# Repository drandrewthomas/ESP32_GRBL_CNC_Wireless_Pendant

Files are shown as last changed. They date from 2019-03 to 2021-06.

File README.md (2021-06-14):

# ESP32 GRBL CNC pendant with Bluetooth data link

## Introduction

I have a small, cheap and cheerful, Chinese CNC machine that I use for routing and LASER cutting. It's really good but one thing it lacked compared to more professional machines was a proper pendant for me to jog and zero the XYZ axes. So, I decided to build one. While thinking about what microcontroller to use it dawned on me that if I used an ESP32 I could combine the pendant functions with a Bluetooth interface for sending G-Code over. After some coding, soldering and 3D printing I ended up with the design shown below.

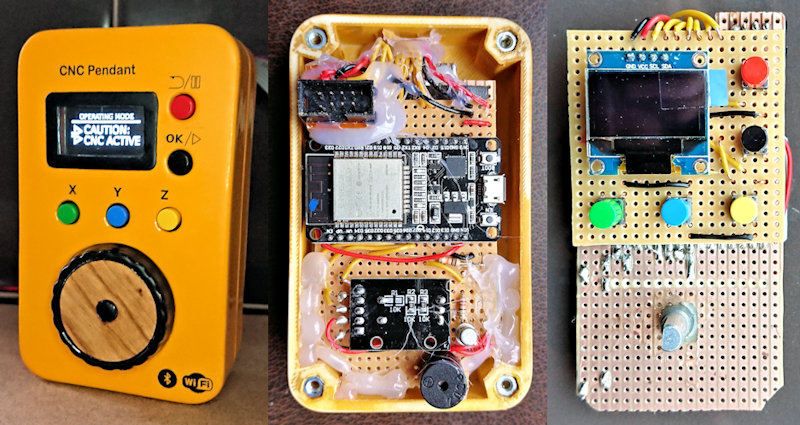
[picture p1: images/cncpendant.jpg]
Photos of the finished pendant and the circuit


## Building the pendant

One of the difficulties with a project like this is that there are a wide range of ESP32 modules available. So, it's not possible to give exact construction details. However, I thought I'd provide a few hints based on my experience designing it. The first is that all of the connections for switches, the OLED display and the rotary encoder module are in the Arduino code. It just involves running wires from those to the ESP32 board. To make life simple I wrote the code to use internal pullup resistors for the buttons. However, not all pins on all ESP32 boards have them, so if you have problems with a button not working you can add a 10k pullup resistor to it (you can see I had to do that with one button in the images folder).

The buzzer is a little more complicated as I used a 5V active one to get enough volume for it to be heard over the CNC machine. As it's 5V, and ESP32s are 3.3V, I used a 2n2222A transistor, with a 220 ohm resistor into it from the ESP32, for switching on and off, which works well. Another difficulty is the serial connection. Obviously you need to connect 5V and ground to the ESP32 (making sure to connect 5V to Vin, not 3.3V) and wire the Tx and Rx serial connections together between the CNC controller and ESP32. However, the connections vary between different GRBL CNC controller boards, so you'll need to sort that out for yourself based on which board you have. And if you have trouble getting output on your OLED display check that it is using I2C address 0x3c: some are set to use 0x3D in which case you need to change it using the solder jumper on the back or, more simply, change the address in the setup() function in the Arduino code. Also, please note that the Adafruit libraries now need you to install their busio library in the Arduino IDE to make them work without raising errors when compiling.

As for the case, it just involves 3D printing the parts provided in the '3d files' folder. You may need to adapt it for your use and for variations between ESP32 boards, so I've included the OpenSCAD file too. The photos should give enough info for you to lay out a piece of stripboard (a.k.a. veroboard) with the OLED display and buttons to fit the case openings. To mount the rotary encoder module I cut a hole in some stripboard and fixed the encoder to the back. The case includes holes in the corners that you can glue M3 nuts into to bolt the top and bottom of the case together. For the dial I decided to LASER cut some 1.5mm thick cherry wood, although you could change the OpenSCAD design to remove the need for that. However, if you decide to cut it there's an SVG included to help you out.

Finally, if your CNC controller board doesn't support 3.3V signals on the UART serial connection, you will need a level-convertor board to interface with the pendant. A cheap two channel one, such as sold for I2C level conversion, should do the job. If your CNC controller board has sufficient current limiting resistors on the serial transmit and receive pins (e.g. some Woodpecker ones have 100 ohm resistors) you may get away without level conversion, but for complete peace of mind it's safest to add level conversion to prevent frying your ESP32 circuits.

## Parts list

The exact parts needed will depend on how you decide to build the project, but the list below is what I used, in case you find it useful:

* 1x 0.96 Inch SSD1306 OLED I2C Display 128x64 pixels

* 5x PCB mounting push switches

* 1x Arduino rotary encoder module brick on PCB

* 1x ESP32 board (I used an ESP32 DOIT DevKit v1)

* 1x 220-ohm resistor

* 1x 2n2222A transistor

* 1x 5V mini active buzzer

* 4x M3 nuts and bolts

* 10 k-ohm pullup resistors for push switches where needed

## Using the pendant

When you power up the pendant (usually through your cable to the CNC controller board) it'll show a splash screen and soon after start in operating mode (as in the photo above). That means it will pass through any commands sent between your PC/tablet and the CNC controller. Basically that means it'll act just like any other wireless or wired way of sending G-Code to your CNC. To connect via Bluetooth you'll need to know the pendants' identifier, which is 'CNCESP32'.

From the operating mode you can use the OK button to access a menu of other functions: jogging mode, zeroing mode and focusing mode. The modes are quite easy to change or add to in the code if they don't suit your needs. Use the rotary encoder dial to scroll through them. The OK button then lets you enter that mode. In jogging mode you can choose the axis to move using the XYZ buttons and turn the dial clockwise and counter-clockwise to move the selected axis. For coarser, faster, movement press the rotary encoder dial down while turning, as the encoder has a switch built in. Coarser movement goes three times further than normal jogging, so please be careful until you get the hang of it.

In zeroing mode you can press an XYZ button and the pendant will tell the CNC controller to zero that axis at the current position. To zero all axes just press the XYZ buttons one at a time, waiting for a confirmation beep in between. The final mode is the focusing one, which is only of use if you have a LASER module. Basically it turns on the LASER at a low power level: I set the value for my 5W dode-LASER so please adjust it to suit your own LASER so as to minimise injury and damage risks. The first time you enter this mode the LASER will turn on, allowing you to focus it or to go back to jogging mode to set your origin position with a visible LASER-dot. The second time will turn the LASER off, although it'll also turn off automatically if you exit back to operating mode (all modes and menus can be exited with the BACK button).

## And finally!

If you'd like to read my blog-post about this project [please click here to visit it](https://cncmakerzone.co.uk/make-a-grbl-cnc-pendant-with-a-bluetooth-data-link).

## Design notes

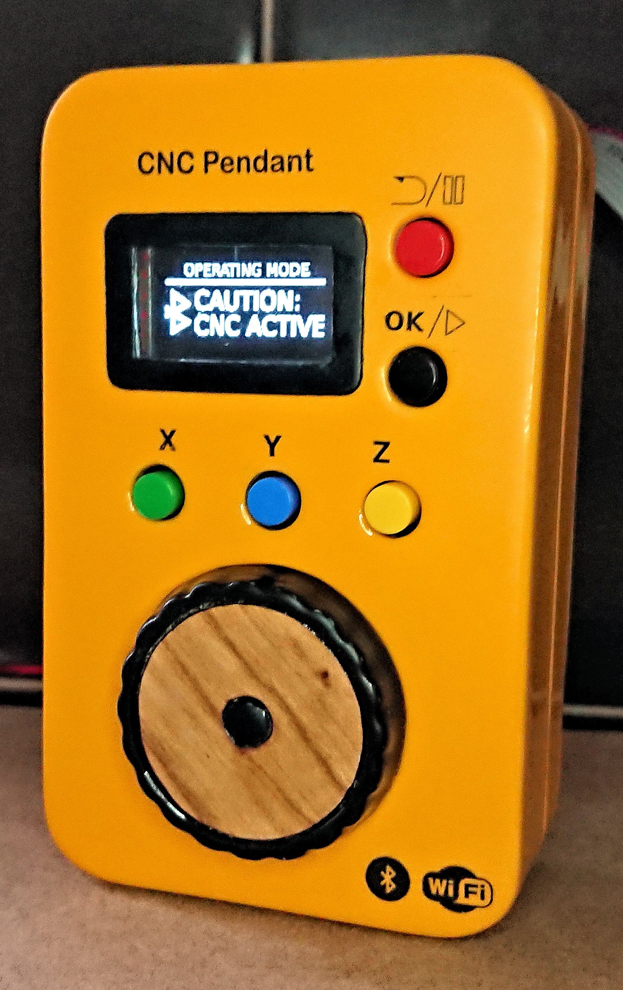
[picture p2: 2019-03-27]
images/cncpendant_front.jpg

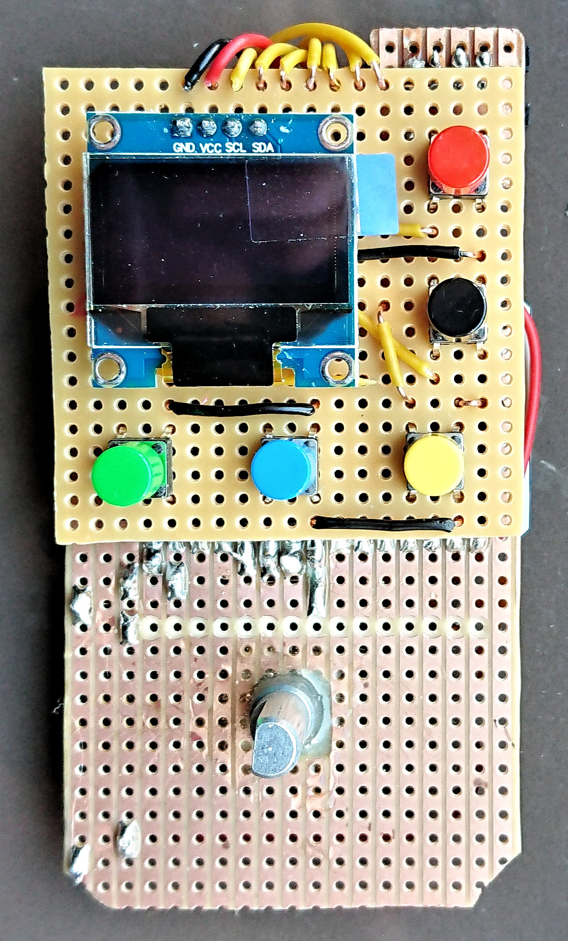
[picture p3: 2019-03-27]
images/cncpendant_layout.jpg

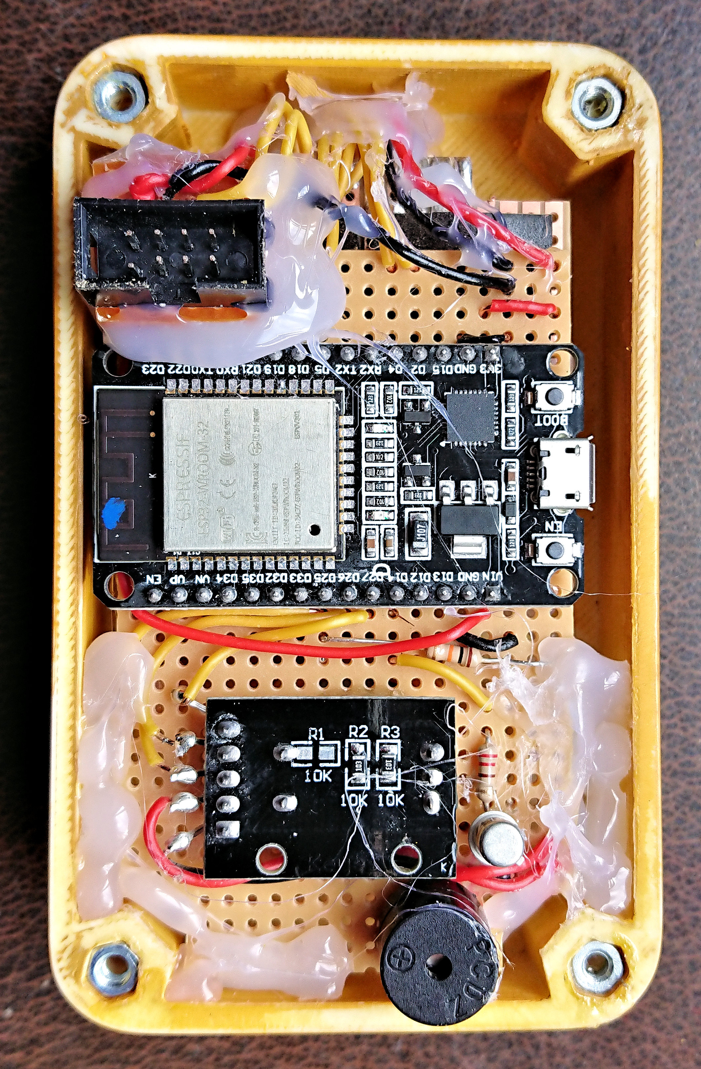
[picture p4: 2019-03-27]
images/cncpendant_inside.jpg

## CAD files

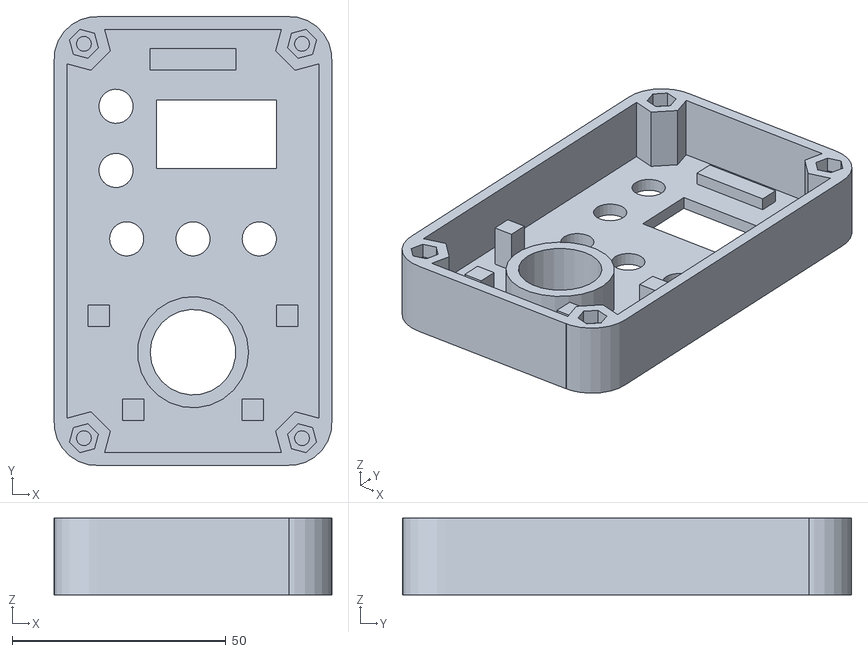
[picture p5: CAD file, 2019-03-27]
3dfiles/cncminipendant_top.stl
65.0 x 105.0 x 18.0

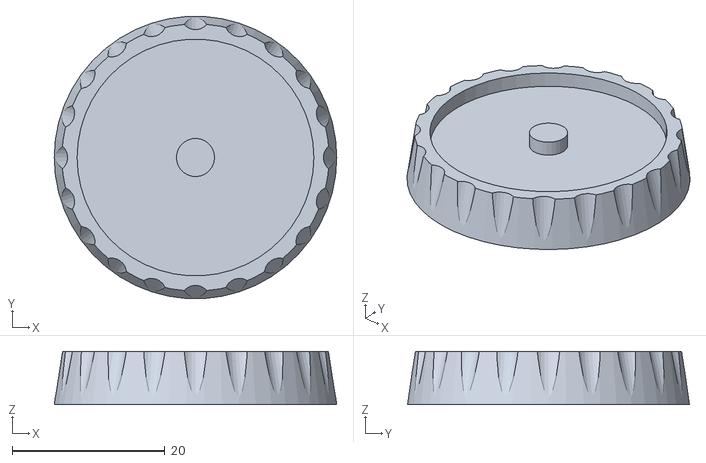
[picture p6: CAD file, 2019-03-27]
3dfiles/cncminipendant_dialtop.stl
37.0 x 36.9 x 7.00

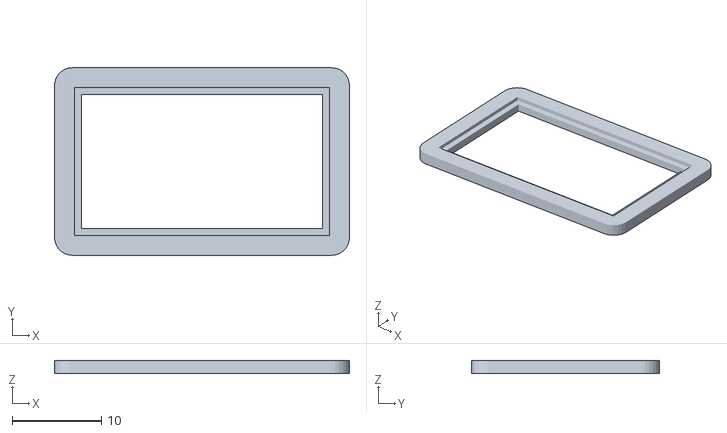
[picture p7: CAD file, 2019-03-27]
3dfiles/cncminipendant_lcdbezel.stl
33.0 x 21.0 x 1.50

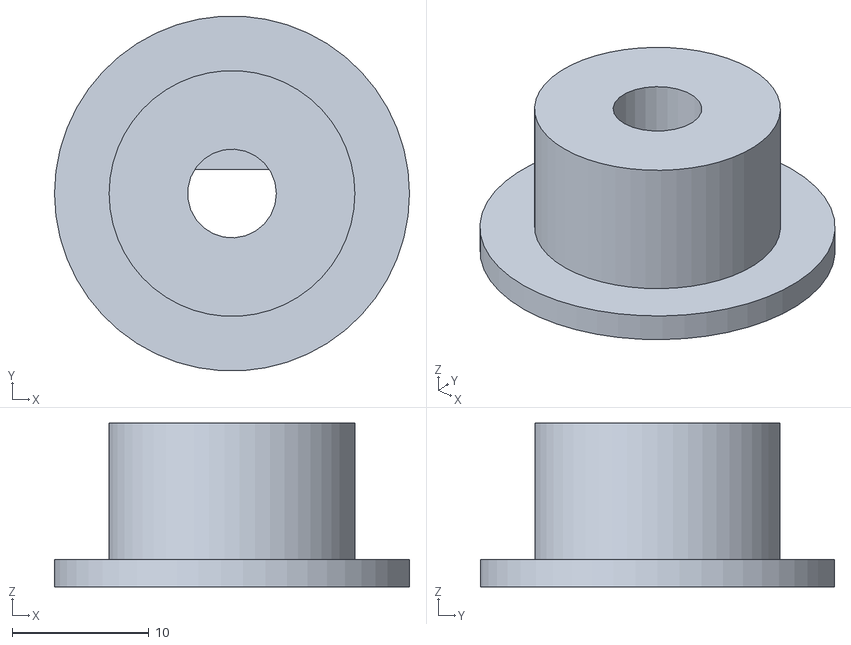
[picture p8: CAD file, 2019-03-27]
3dfiles/cncminipendant_dialbase.stl
26.0 x 25.9 x 12.0

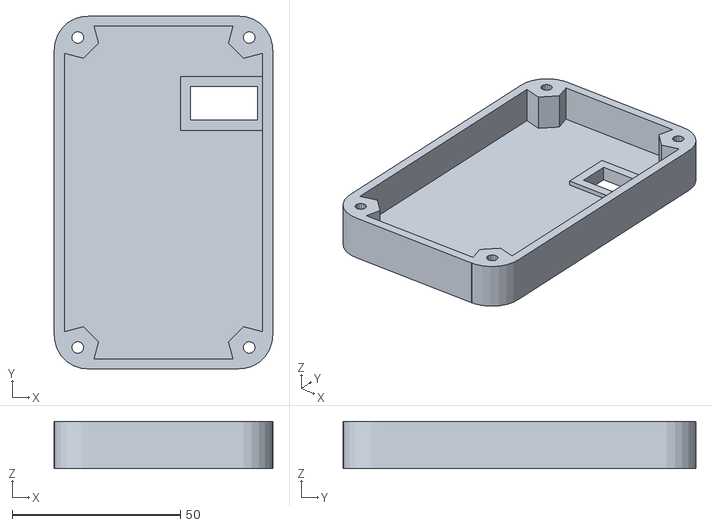
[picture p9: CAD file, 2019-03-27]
3dfiles/cncminipendant_bottom.stl
65.0 x 105.0 x 14.0

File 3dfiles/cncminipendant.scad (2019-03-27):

$fn=25;

//maketop();
//makelcdbezel();
//makedialbase();
//makedialtop();
makebottom();

module makebottom()
{
  render() difference()
  {
    render() union()
    {
      render() difference()
      {
        translate([0,-0.5,0]) roundedbox(55+4+6,96+3+6,14,10);
        translate([0,-0.5,3]) roundedbox(55+4,96+3,14,7);
      }
      translate([32-10-4,52.5-0.5-5-21,-5.5+1.9]) cube([26,16,2],center=true);
      translate([-24-1.5,(96/2)-0.5-1.9,0]) rotate([0,0,45]) cylinder(h=14,r1=12.8/2,r2=12.8/2,$fn=6,center=true);
      translate([24+1.5,(96/2)-0.5-1.9,0]) rotate([0,0,-45]) cylinder(h=14,r1=12.8/2,r2=12.8/2,$fn=6,center=true);
      translate([-24-1.5,-(96/2)-0.5+1.9,0]) rotate([0,0,15]) cylinder(h=14,r1=12.8/2,r2=12.8/2,$fn=6,center=true);
      translate([24+1.5,-(96/2)-0.5+1.9,0]) rotate([0,0,-15]) cylinder(h=14,r1=12.8/2,r2=12.8/2,$fn=6,center=true);
    }
    translate([-24-1.5,(96/2)-0.5-1.9,0]) cylinder(h=20,r1=3.5/2,r2=3.5/2,$fn=15,center=true);
    translate([24+1.5,(96/2)-0.5-1.9,0]) cylinder(h=20,r1=3.5/2,r2=3.5/2,$fn=15,center=true);
    translate([-24-1.5,-(96/2)-0.5+1.9,0]) cylinder(h=20,r1=3.5/2,r2=3.5/2,$fn=15,center=true);
    translate([24+1.5,-(96/2)-0.5+1.9,0]) cylinder(h=20,r1=3.5/2,r2=3.5/2,$fn=15,center=true);
    render() difference()
    {
      translate([0,-0.5,0]) roundedbox(100+55+4+6,100+96+3+6,18,10);
      translate([0,-0.5,0]) roundedbox(55+4+6,96+3+6,100,10);
    }
    translate([32-10-4,52.5-0.5-5-21,0]) cube([20,10,20],center=true);
  }
}

module makedialtop()
{
  union()
  {
    difference()
    {
      translate([0,0,0]) cylinder(h=7,r1=37/2,r2=35/2,$fn=50,center=true);
      translate([0,0,-3.5]) cylinder(h=6,r1=26.5/2,r2=26.5/2,$fn=50,center=true);
      translate([0,0,3.5]) cylinder(h=4,r1=31/2,r2=31/2,$fn=50,center=true);
      for(c=[0:20])
        rotate([0,0,c*(360/20)])
          translate([-19.75,0,0])
            rotate([0,15,0])
              cylinder(h=30,r1=4/2,r2=4/2,$fn=25,center=true);
    }
    translate([0,0,3.5-1.1]) cylinder(h=2.1,r1=5/2,r2=5/2,$fn=25,center=true);
  }
}

module makedialbase()
{
  rotate([180,0,0])
  {
    difference()
    {
      union()
      {
        translate([0,0,1]) cylinder(h=12,r1=18/2,r2=18/2,$fn=50,center=true);
        translate([0,0,1+6-1]) cylinder(h=2,r1=26/2,r2=26/2,$fn=50,center=true);
      }
      difference()
      {
        translate([0,0,0]) cylinder(h=20,r1=6.5/2,r2=6.5/2,center=true);
        translate([0,-(6.5/2)-0.5,10-1]) cube([10,4,20],center=true);
      }
    }
  }
}

module makelcdbezel()
{
  rotate([0,180,0])
  {
    difference()
    {
      translate([0,0,0]) roundedbox(27+6,15+6,1.5,2);
      translate([0,0,0]) cube([27,15,50],center=true);
      translate([0,0,-1]) cube([27+1.5,15+1.5,1.5],center=true);
    }
  }
}

module maketop()
{
  difference()
  {
    union()
    {
      difference()
      {
        translate([0,-0.5,0]) roundedbox(55+4+6,96+3+6,18,10);
        translate([0,-0.5,3]) roundedbox(55+4,96+3,18,7);
      }
      translate([0,-(96/2)+48-26.5,-9+5+1.5]) cylinder(h=10+3,r1=26/2,r2=26/2,$fn=25,center=true);
      translate([-14,-40,-9+5+1.5]) cube([5,5,10+3],center=true);
      translate([14,-40,-9+5+1.5]) cube([5,5,10+3],center=true);
      translate([-22,-18,-9+5+1.5]) cube([5,5,10+3],center=true);
      translate([22,-18,-9+5+1.5]) cube([5,5,10+3],center=true);
      translate([0,42,-9+1.5+1.5]) cube([20,5,3+3],center=true);
      translate([-24-1.5,(96/2)-0.5-1.9,0]) rotate([0,0,45]) cylinder(h=18,r1=12.8/2,r2=12.8/2,$fn=6,center=true);
      translate([24+1.5,(96/2)-0.5-1.9,0]) rotate([0,0,-45]) cylinder(h=18,r1=12.8/2,r2=12.8/2,$fn=6,center=true);
      translate([-24-1.5,-(96/2)-0.5+1.9,0]) rotate([0,0,15]) cylinder(h=18,r1=12.8/2,r2=12.8/2,$fn=6,center=true);
      translate([24+1.5,-(96/2)-0.5+1.9,0]) rotate([0,0,-15]) cylinder(h=18,r1=12.8/2,r2=12.8/2,$fn=6,center=true);
    }
    translate([0,0,0]) rotate([0,180,0]) controls();
    translate([-24-1.5,(96/2)-0.5-1.9,18-3.5]) rotate([0,0,45]) cylinder(h=18,r1=7/2,r2=7/2,$fn=6,center=true);
    translate([24+1.5,(96/2)-0.5-1.9,18-3.5]) rotate([0,0,-45]) cylinder(h=18,r1=7/2,r2=7/2,$fn=6,center=true);
    translate([-24-1.5,-(96/2)-0.5+1.9,18-3.5]) rotate([0,0,15]) cylinder(h=18,r1=7/2,r2=7/2,$fn=6,center=true);
    translate([24+1.5,-(96/2)-0.5+1.9,18-3.5]) rotate([0,0,-15]) cylinder(h=18,r1=7/2,r2=7/2,$fn=6,center=true);
    translate([-24-1.5,(96/2)-0.5-1.9,5]) cylinder(h=18,r1=3.5/2,r2=3.5/2,$fn=15,center=true);
    translate([24+1.5,(96/2)-0.5-1.9,5]) cylinder(h=18,r1=3.5/2,r2=3.5/2,$fn=15,center=true);
    translate([-24-1.5,-(96/2)-0.5+1.9,5]) cylinder(h=18,r1=3.5/2,r2=3.5/2,$fn=15,center=true);
    translate([24+1.5,-(96/2)-0.5+1.9,5]) cylinder(h=18,r1=3.5/2,r2=3.5/2,$fn=15,center=true);
    difference()
    {
      translate([0,-0.5,0]) roundedbox(100+55+4+6,100+96+3+6,18,10);
      translate([0,-0.5,0]) roundedbox(55+4+6,96+3+6,100,10);
    }
  }
}

module controls()
{
  translate([-(55/2)+5+(27/2)+4.5-1,-(96/2)+65.5+(15/2)-0.5,0]) cube([27+1,15+1,50],center=true);
  translate([(55/2)-9.5,-(96/2)+79,0]) cylinder(h=50,r1=8/2,r2=8/2,center=true);
  translate([(55/2)-9.5,-(96/2)+64,0]) cylinder(h=50,r1=8/2,r2=8/2,center=true);
  translate([-15.5,-(96/2)+48,0]) cylinder(h=50,r1=8/2,r2=8/2,center=true);
  translate([0,-(96/2)+48,0]) cylinder(h=50,r1=8/2,r2=8/2,center=true);
  translate([15.5,-(96/2)+48,0]) cylinder(h=50,r1=8/2,r2=8/2,center=true);
  translate([0,-(96/2)+48-26.5,0]) cylinder(h=50,r1=20/2,r2=20/2,$fn=25,center=true);
}

module roundedbox(l,d,h,r)
{
  difference()
  {
    difference()
    {
      difference()
      {
        difference()
        {
          cube([l,d,h],center=true);
          translate([-(l/2)+r,-(d/2)+r,0]){corner(r,h,0);};
        }
        translate([(l/2)-r,-(d/2)+r,0]){corner(r,h,90);};
      }
      translate([(l/2)-r,(d/2)-r,0]){corner(r,h,180);};
    }
    translate([-(l/2)+r,(d/2)-r,0]){corner(r,h,270);};
  }
}

module corner(r,h,ang)
{
  rotate([0,0,ang])
  {
    difference()
    {
      difference()
      {
        difference()
        {
          cylinder(h*2,r*2,r*2,center=true);
          cylinder(h*2,r,r,center=true);
        }
        translate([r*5,0,0]){cube([r*10,r*10,h*2],center=true);}
      }
      translate([0,r*5,0]){cube([r*10,r*10,h*2],center=true);}
    }
  }
}

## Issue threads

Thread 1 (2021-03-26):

Blank screen after uploaded successfully

RepRapThailand, 2021-03-26:
Hello,

  I tried many times to upload your sketch, but it failed every time. When I try to upload sample sketch "ssd1306_128x32_i2c" and success every time there is a picture on the screen.

 Best Regards,

**Blank screen with your sketch.**

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

**ssd1306_128x32_i2c  sketch.**

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

drandrewthomas, 2021-03-26:
Hi,

Sorry to hear you're having problems. I checked and my I2C wiring seems the same as yours, so odd yours didn't work. So could you try the three ideas below (my guess is it's number 3):

1. Have you used the serial console to see if the library is printing an error?

2. If you look in setup() you'll see the pinMode lines. The ones that have INPUT, rather than INPUT_PULLUP, will have floating voltages unless you use 10k pullup resistors on those pins. That could interfere with operation so I can't guarantee the code will work unless you build the full circuit.

3. I was a bit confused by your screenshot of the example code, as it suggests you're using code for a 128x32 oled, which I think often have an I2C address of 0x3D. Looking at one of my OLED displays I notice it has an address changing jumper on the back that seems to be set for 0x3D. So can you check what address your oled is set to (or you could use the arduino i2c detect sketch). My guess is that changing the 0x3C address in setup(), for the oled setup line, to 0x3D will solve your problem.

Let me know if that helps, or if you still get a problem.

Best wishes,

Andrew.

RepRapThailand, 2021-03-27:
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

Hi,

1.
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

2. Not try yet.

3. I try with ssd1306_128x64_i2c sketch and it work too. I use Arduino i2c detect sketch scan my OLED and it show 0x3C.

Best Regards,
KK.

RepRapThailand, 2021-03-27:
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

#include <Wire.h>
#include <Adafruit_GFX.h>
#include <Adafruit_SSD1306.h>
#define SCREEN_WIDTH 128
#define SCREEN_HEIGHT 64
Adafruit_SSD1306 display(SCREEN_WIDTH, SCREEN_HEIGHT, &Wire, -1);
static const uint8_t image_data[1024] = {
   0xff, 0xff, 0xff, 0xff, 0xff, 0xff, 0xff, 0xff, 0xff, 0xff, 0xff, 0xff, 0xff, 0xff, 0xff, 0xff,
0xff, 0xff, 0xff, 0xff, 0xff, 0xff, 0xff, 0xff, 0xff, 0xff, 0xff, 0xff, 0xff, 0xff, 0xff, 0xff,
0xff, 0xff, 0xff, 0xff, 0xff, 0xff, 0xff, 0xff, 0xff, 0xff, 0xff, 0xff, 0xff, 0xff, 0xff, 0xff,
0xff, 0xff, 0xff, 0xff, 0xff, 0xff, 0xff, 0xff, 0xff, 0xff, 0xff, 0xff, 0xff, 0xff, 0xff, 0xff,
0xff, 0xff, 0xff, 0xff, 0xff, 0xff, 0xff, 0xff, 0xff, 0xff, 0xff, 0xff, 0xff, 0xff, 0xff, 0xff,
0xff, 0xff, 0xff, 0xff, 0xff, 0xff, 0xff, 0xff, 0xff, 0xff, 0xff, 0xff, 0xff, 0xff, 0xff, 0xff,
0xff, 0xff, 0xff, 0xff, 0xff, 0xff, 0xff, 0xff, 0xff, 0xff, 0xff, 0xff, 0xff, 0xff, 0xff, 0xff,
0xff, 0xff, 0xff, 0xff, 0xff, 0xff, 0xff, 0xff, 0xff, 0xff, 0xff, 0xff, 0xff, 0xff, 0xff, 0xff,
0xff, 0xff, 0xff, 0xff, 0xff, 0xfb, 0xff, 0xff, 0xff, 0xff, 0xdf, 0xff, 0xff, 0xff, 0xff, 0xff,
0xff, 0xff, 0xff, 0xff, 0xfc, 0x00, 0x00, 0xff, 0xff, 0x00, 0x00, 0x3f, 0xff, 0xff, 0xff, 0xff,
0xff, 0xff, 0xff, 0xff, 0xe0, 0x00, 0x00, 0x1f, 0xf8, 0x00, 0x00, 0x07, 0xff, 0xff, 0xff, 0xff,
0xff, 0xff, 0xff, 0xff, 0xf0, 0x20, 0x00, 0x0f, 0xf0, 0x00, 0x04, 0x0f, 0xff, 0xff, 0xff, 0xff,
0xff, 0xff, 0xff, 0xff, 0xf0, 0x0e, 0x00, 0x07, 0xe0, 0x00, 0x60, 0x0f, 0xff, 0xff, 0xff, 0xff,
0xff, 0xff, 0xff, 0xff, 0xe0, 0x01, 0xe0, 0x03, 0xc0, 0x07, 0x80, 0x07, 0xff, 0xff, 0xff, 0xff,
0xff, 0xff, 0xff, 0xff, 0xf8, 0x00, 0x3c, 0x03, 0xc0, 0x3c, 0x00, 0x1f, 0xff, 0xff, 0xff, 0xff,
0xff, 0xff, 0xff, 0xff, 0xf8, 0x00, 0x07, 0x87, 0xe1, 0xe0, 0x00, 0x1f, 0xff, 0xff, 0xff, 0xff,
0xff, 0xff, 0xff, 0xff, 0xfe, 0x00, 0x01, 0xff, 0xff, 0x80, 0x00, 0x7f, 0xff, 0xff, 0xff, 0xff,
0xff, 0xff, 0xff, 0xff, 0xff, 0x00, 0x00, 0x7f, 0xfe, 0x00, 0x00, 0xff, 0xff, 0xff, 0xff, 0xff,
0xff, 0xff, 0xff, 0xff, 0xff, 0x80, 0x00, 0xff, 0xff, 0x00, 0x01, 0xff, 0xff, 0xff, 0xff, 0xff,
0xff, 0xff, 0xff, 0xff, 0xff, 0xf0, 0x01, 0xff, 0xff, 0x80, 0x0f, 0xff, 0xff, 0xff, 0xff, 0xff,
0xff, 0xff, 0xff, 0xff, 0xff, 0xfe, 0x3f, 0xff, 0xff, 0xfc, 0x7f, 0xff, 0xff, 0xff, 0xff, 0xff,
0xff, 0xff, 0xff, 0xff, 0xff, 0xff, 0xff, 0xf0, 0x0f, 0xff, 0xff, 0xff, 0xff, 0xff, 0xff, 0xff,
0xff, 0xff, 0xff, 0xff, 0xff, 0xfc, 0x0f, 0x80, 0x01, 0xc0, 0x7f, 0xff, 0xff, 0xff, 0xff, 0xff,
0xff, 0xff, 0xff, 0xff, 0xff, 0xe0, 0x1e, 0x00, 0x00, 0x60, 0x0f, 0xff, 0xff, 0xff, 0xff, 0xff,
0xff, 0xff, 0xff, 0xff, 0xff, 0x80, 0x3e, 0x00, 0x00, 0x78, 0x03, 0xff, 0xff, 0xff, 0xff, 0xff,
0xff, 0xff, 0xff, 0xff, 0xfe, 0x00, 0xff, 0x00, 0x00, 0xfe, 0x01, 0xff, 0xff, 0xff, 0xff, 0xff,
0xff, 0xff, 0xff, 0xff, 0xfe, 0x03, 0xff, 0xe0, 0x03, 0xff, 0x80, 0xff, 0xff, 0xff, 0xff, 0xff,
0xff, 0xff, 0xff, 0xff, 0xfc, 0x0f, 0xff, 0xff, 0xff, 0xff, 0xe0, 0x7f, 0xff, 0xff, 0xff, 0xff,
0xff, 0xff, 0xff, 0xff, 0xfc, 0x7f, 0x00, 0x3f, 0xf8, 0x00, 0xfc, 0x7f, 0xff, 0xff, 0xff, 0xff,
0xff, 0xff, 0xff, 0xff, 0xff, 0xfc, 0x00, 0x0f, 0xf0, 0x00, 0x3f, 0xff, 0xff, 0xff, 0xff, 0xff,
0xff, 0xff, 0xff, 0xff, 0xff, 0xf8, 0x00, 0x07, 0xe0, 0x00, 0x1f, 0xff, 0xff, 0xff, 0xff, 0xff,
0xff, 0xff, 0xff, 0xff, 0xf3, 0xf0, 0x00, 0x07, 0xc0, 0x00, 0x0f, 0x8f, 0xff, 0xff, 0xff, 0xff,
0xff, 0xff, 0xff, 0xff, 0xc3, 0xe0, 0x00, 0x03, 0xc0, 0x00, 0x07, 0x03, 0xff, 0xff, 0xff, 0xff,
0xff, 0xff, 0xff, 0xff, 0x01, 0xc0, 0x00, 0x03, 0xc0, 0x00, 0x07, 0x01, 0xff, 0xff, 0xff, 0xff,
0xff, 0xff, 0xff, 0xff, 0x01, 0xc0, 0x00, 0x07, 0xe0, 0x00, 0x07, 0x01, 0xff, 0xff, 0xff, 0xff,
0xff, 0xff, 0xff, 0xfe, 0x01, 0xc0, 0x00, 0x07, 0xf0, 0x00, 0x07, 0x80, 0xff, 0xff, 0xff, 0xff,
0xff, 0xff, 0xff, 0xfe, 0x03, 0xe0, 0x00, 0x0f, 0xf8, 0x00, 0x0f, 0x80, 0xff, 0xff, 0xff, 0xff,
0xff, 0xff, 0xff, 0xfe, 0x03, 0xf0, 0x00, 0x3f, 0xfc, 0x00, 0x1f, 0x80, 0xff, 0xff, 0xff, 0xff,
0xff, 0xff, 0xff, 0xff, 0x07, 0xfc, 0x00, 0xff, 0xff, 0x80, 0x3f, 0xc1, 0xff, 0xff, 0xff, 0xff,
0xff, 0xff, 0xff, 0xff, 0x87, 0xff, 0xff, 0xc0, 0x03, 0xff, 0xff, 0xc3, 0xff, 0xff, 0xff, 0xff,
0xff, 0xff, 0xff, 0xff, 0xcf, 0xff, 0xff, 0x00, 0x00, 0xff, 0xff, 0xf7, 0xff, 0xff, 0xff, 0xff,
0xff, 0xff, 0xff, 0xff, 0xfe, 0x3f, 0xfe, 0x00, 0x00, 0x7f, 0xe0, 0x3f, 0xff, 0xff, 0xff, 0xff,
0xff, 0xff, 0xff, 0xff, 0xf8, 0x07, 0xfc, 0x00, 0x00, 0x3f, 0x80, 0x1f, 0xff, 0xff, 0xff, 0xff,
0xff, 0xff, 0xff, 0xff, 0xf8, 0x01, 0xfc, 0x00, 0x00, 0x3e, 0x00, 0x1f, 0xff, 0xff, 0xff, 0xff,
0xff, 0xff, 0xff, 0xff, 0xf8, 0x00, 0x7c, 0x00, 0x00, 0x3c, 0x00, 0x1f, 0xff, 0xff, 0xff, 0xff,
0xff, 0xff, 0xff, 0xff, 0xf8, 0x00, 0x3c, 0x00, 0x00, 0x38, 0x00, 0x1f, 0xff, 0xff, 0xff, 0xff,
0xff, 0xff, 0xff, 0xff, 0xf8, 0x00, 0x1e, 0x00, 0x00, 0x70, 0x00, 0x3f, 0xff, 0xff, 0xff, 0xff,
0xff, 0xff, 0xff, 0xff, 0xfc, 0x00, 0x1f, 0x80, 0x01, 0xf0, 0x00, 0x3f, 0xff, 0xff, 0xff, 0xff,
0xff, 0xff, 0xff, 0xff, 0xfe, 0x00, 0x0f, 0xe0, 0x07, 0xe0, 0x00, 0xff, 0xff, 0xff, 0xff, 0xff,
0xff, 0xff, 0xff, 0xff, 0xff, 0x80, 0x0f, 0xff, 0xff, 0xf0, 0x03, 0xff, 0xff, 0xff, 0xff, 0xff,
0xff, 0xff, 0xff, 0xff, 0xff, 0xf0, 0x1f, 0xff, 0xff, 0xf0, 0x0f, 0xff, 0xff, 0xff, 0xff, 0xff,
0xff, 0xff, 0xff, 0xff, 0xff, 0xff, 0xff, 0xc0, 0x03, 0xff, 0xff, 0xff, 0xff, 0xff, 0xff, 0xff,
0xff, 0xff, 0xff, 0xff, 0xff, 0xff, 0xfe, 0x00, 0x00, 0x7f, 0xff, 0xff, 0xff, 0xff, 0xff, 0xff,
0xff, 0xff, 0xff, 0xff, 0xff, 0xff, 0xfc, 0x00, 0x00, 0x7f, 0xff, 0xff, 0xff, 0xff, 0xff, 0xff,
0xff, 0xff, 0xff, 0xff, 0xff, 0xff, 0xff, 0x00, 0x00, 0xff, 0xff, 0xff, 0xff, 0xff, 0xff, 0xff,
0xff, 0xff, 0xff, 0xff, 0xff, 0xff, 0xff, 0xc0, 0x07, 0xff, 0xff, 0xff, 0xff, 0xff, 0xff, 0xff,
0xff, 0xff, 0xff, 0xff, 0xff, 0xff, 0xff, 0xff, 0xff, 0xff, 0xff, 0xff, 0xff, 0xff, 0xff, 0xff,
0xff, 0xff, 0xff, 0xff, 0xff, 0xff, 0xff, 0xff, 0xff, 0xff, 0xff, 0xff, 0xff, 0xff, 0xff, 0xff,
0xff, 0xff, 0xff, 0xff, 0xff, 0xff, 0xff, 0xff, 0xff, 0xff, 0xff, 0xff, 0xff, 0xff, 0xff, 0xff,
0xff, 0xff, 0xff, 0xff, 0xff, 0xff, 0xff, 0xff, 0xff, 0xff, 0xff, 0xff, 0xff, 0xff, 0xff, 0xff,
0xff, 0xff, 0xff, 0xff, 0xff, 0xff, 0xff, 0xff, 0xff, 0xff, 0xff, 0xff, 0xff, 0xff, 0xff, 0xff,
0xff, 0xff, 0xff, 0xff, 0xff, 0xff, 0xff, 0xff, 0xff, 0xff, 0xff, 0xff, 0xff, 0xff, 0xff, 0xff,
0xff, 0xff, 0xff, 0xff, 0xff, 0xff, 0xff, 0xff, 0xff, 0xff, 0xff, 0xff, 0xff, 0xff, 0xff, 0xff,
0xff, 0xff, 0xff, 0xff, 0xff, 0xff, 0xff, 0xff, 0xff, 0xff, 0xff, 0xff, 0xff, 0xff, 0xff, 0xff
};
void setup() {
  Serial.begin(115200);
  if(!display.begin(SSD1306_SWITCHCAPVCC, 0x3C)) {
    Serial.println(F("SSD1306 allocation failed"));
    for(;;);
  }
  delay(2000); // Pause for 2 seconds
  // Clear the buffer.
   display.clearDisplay();
  testscrolltext();
  // Clear the buffer.
  display.clearDisplay();
  // Draw bitmap on the screen
  display.drawBitmap(0, 0, image_data, 128, 64, 1);
  display.display();
}
 void testscrolltext(void) {
  display.clearDisplay(); // clear the display screen of the OLED
  display.setTextSize(2); // Draw 2X-scale text
  display.setTextColor(WHITE);
  display.setCursor(0, 0);
  display.println(F("Welcome"));
  delay(2000);
  display.clearDisplay();
  display.println(F("Coming Up"));
  display.println(F("RPi logo"));
  display.display();
  delay(100);
  display.startscrollright(0x00, 0x0F);
  delay(2000);
  display.stopscroll();
  delay(1000);
  display.startscrollleft(0x00, 0x0F);
  delay(2000);
  display.stopscroll();
  delay(1000);
  display.startscrolldiagright(0x00, 0x07);
  delay(2000);
  display.startscrolldiagleft(0x00, 0x07);
  delay(2000);
  display.stopscroll();
  delay(1000);
}
void loop() {
}

RepRapThailand, 2021-03-27:
not success..

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

#include <SPI.h>
#include <Wire.h>
#include <Adafruit_GFX.h>
#include <Adafruit_SSD1306.h>

Adafruit_SSD1306 display(-1);
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
drandrewthomas, 2021-03-27:
Hi,

Thanks for trying that and for the info. I wired up an OLED to the same ESP32 board as you, with the same wiring, and the latest stable Arduino IDE, and it worked! So I was a bit confused!! So I decided to update to the latest Adafruit_SSD1306 and Adafruit_GFX library versions on Github (which now also require their busio library as a dependancy) and it didn't work!!!

So it turns out the new Adafruit_SSD1306 library requires the display to be declared differently to previously, with the line:

Adafruit_SSD1306 display(0);

now having to be:

Adafruit_SSD1306 display(128,64,&Wire,0);

That's all I had to change to get it working in the end. It's unusual for a library to completely change the way things are declared otherwise I'd probably have worked it out sooner. But anyway I've amended the Arduino code so if you download it again you should find it works OK (the change is at line 34). However, I'd still recommend you build the complete circuit as it is possible that the code could occasionally do something wrong just because of floating voltages on pins (or change the code, or add pullups, of course).

I also changed the main README.md file to add some info about I2C addresses and the new need for the busio library, which will hopefully help others. Anyway, could you please let me know if that clears up all your issues?

Thanks,

Andrew.

Closed 2021-04-28.

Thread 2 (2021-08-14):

Bluetooth host

WadeRobot, 2021-08-14:
Hello, this is a very good project. Can I connect with GRBL ESP32 through Bluetooth as the host? [https://github.com/bdring/Grbl_Esp32/wiki/Using-Bluetooth](url)

drandrewthomas, 2021-08-14:
Hi, I'm not really sure what you're asking, but if you mean can it send via bluetooth to the board you linked to then no, as the pendant is a bluetooth slave. I suppose you could modify the pendant code but the board you linked to already has a bluetooth interface so it doesn't seem a good idea. The pendant here talks to GRBL boards via serial UART so if that board supports UART you could possibly still connect it as the linked board says it supports all GRBL commands. However, I really can't say as I have no experience of that board and the pendant is really for CNC machines that don't have bluetooth (although you could use it just as a simple pendant without using the bluetooth). Best wishes, Andrew.

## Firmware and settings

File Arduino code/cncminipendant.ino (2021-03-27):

// Convert PNG images at http://javl.github.io/image2cpp/
// 250 threshold and invert colors

// Change to suit your LASER:
#define FOCUSGRBL "M3 S5"

#include "Arduino.h"
#include <Wire.h>
#include "cncimages.h";
#include "BluetoothSerial.h"
#include <Adafruit_GFX.h>
#include <Adafruit_SSD1306.h>
// Adafruit busio library must now be installed in library manager too

#if !defined(CONFIG_BT_ENABLED) || !defined(CONFIG_BLUEDROID_ENABLED)
#error Bluetooth is not enabled! Please run `make menuconfig` to and enable it
#endif

#define ROTARY_A 27
#define ROTARY_B 26
#define ROTARY_SW 25
#define SW_1 19
#define SW_2 18
#define SW_3 5
#define SW_4 4
#define SW_5 2
#define BUZZER 14

BluetoothSerial SerialBT;
int modenum=0,beeplen=0,rotary_alast,rotary_swlast,jogaxis,currfunc=0;
bool sw1=false,sw2=false,sw3=false,firsttime=false,beeping=false;
bool sw1changed=false,sw2changed=false,sw3changed=false,laseron=false;
long beepstart;
Adafruit_SSD1306 display(128,64,&Wire,0);

void setup()
{
  pinMode (ROTARY_A,INPUT);
  pinMode (ROTARY_B,INPUT);
  pinMode (ROTARY_SW,INPUT);
  pinMode (SW_1,INPUT_PULLUP);
  pinMode (SW_2,INPUT_PULLUP);
  pinMode (SW_3,INPUT_PULLUP);
  pinMode (SW_4,INPUT_PULLUP);
  pinMode (SW_5,INPUT);
  pinMode (BUZZER,OUTPUT);
  Serial.begin(115200);
  SerialBT.begin("CNCESP32");
  display.begin(SSD1306_SWITCHCAPVCC,0x3C); // Some displays may be 0x3D
  display.clearDisplay();
  display.drawBitmap(0,0,splash_bmp,splash_width,splash_height,WHITE);
  display.display();
  delay(2000);
  display.clearDisplay();
  drawmode0();
  rotary_alast=digitalRead(ROTARY_A);
  rotary_swlast=digitalRead(ROTARY_SW);
  startbeeping(100);
}

void loop()
{
  if(beeping==true)
  {
    if((millis()-beepstart)>beeplen)
    {
      digitalWrite(BUZZER,LOW);
      beeping=false;
    }
  }
  if(modenum==0)
  {
    if(firsttime==true)
    {
      firsttime=false;
      while(Serial.available()>0) Serial.read();
      while(SerialBT.available()>0) SerialBT.read();
      drawmode0();
    }
    if(Serial.available()>0 || SerialBT.available()>0)
    {
      if(Serial.available()>0)
      {
        SerialBT.write(Serial.read());
      }
      if(SerialBT.available()>0)
      {
        Serial.write(SerialBT.read());
      }
    }
    if(checkbuttons()==2) // OK button is pressed
    {
      modenum=1; // Go to function chooser
      firsttime=true;
    }
  }
  else
  {
    switch(modenum)
    {
      case 1: drawfunctionchooser();
              break;
      case 2: drawjoggingmode();
              break;
      case 3: drawzeroingmode();
              break;
      case 4: drawfocusingmode();
              break;
    }
  }
}

void drawfunctionchooser()
{
  int rotary;
  if(firsttime==true)
  {
    firsttime=false;
    drawfuncscreen();
    delay(50);
    while(checkbuttons()==2); // Check button debounce
    startbeeping(50);
  }
  rotary=rotarycount(200);
  if(rotary>1)
  {
    currfunc++;
    if(currfunc>2) currfunc=0;
    drawfuncscreen();
  }
  if(rotary<-1)
  {
    currfunc--;
    if(currfunc<0) currfunc=2;
    drawfuncscreen();
  }
  if(checkbuttons()==1)
  {
    delay(50);
    while(checkbuttons()==1); // Check button debounce
    modenum=0;
    firsttime=true;
    if(laseron==true)
    {
      Serial.println("M5");
      waitforline();
      laseron=false;
    }
    startbeeping(50);
    return;
  }
  if(checkbuttons()==2)
  {
    delay(50);
    while(checkbuttons()==2); // Check button debounce
    modenum=currfunc+2;
    firsttime=true;
    return;
  }
}

void drawfuncscreen()
{
  display.clearDisplay();
  switch(currfunc)
  {
    case 0: display.drawBitmap(0,0,jogmodefunc_bmp,jogmodefunc_width,jogmodefunc_height,WHITE);
            break;
    case 1: display.drawBitmap(0,0,zeromodefunc_bmp,zeromodefunc_width,zeromodefunc_height,WHITE);
            break;
    case 2: display.drawBitmap(0,0,focusmodefunc_bmp,focusmodefunc_width,focusmodefunc_height,WHITE);
            break;
  }
  display.display();
}

void drawmode0()
{
  display.clearDisplay();
  display.drawBitmap(0,0,mode0bt_bmp,mode0bt_width,mode0bt_height,WHITE);
  display.display();
}

void drawjoggingmode()
{
  int rotary,jogdir;
  float jogdist;
  if(firsttime==true)
  {
    firsttime=false;
    jogaxis=0;
    startbeeping(50);
    drawjoggingdisplay('?');
  }
  if(checkbuttons()==1)
  {
    delay(50);
    while(checkbuttons()==1); // Check button debounce
    modenum=1;
    firsttime=true;
    startbeeping(50);
    return;
  }
  if(checkbuttons()==3) // X button pressed
  {
    delay(50);
    while(checkbuttons()==3); // Check button debounce
    startbeeping(50);
    jogaxis=1;
    drawjoggingdisplay('X');
  }
  if(checkbuttons()==4) // Y button pressed
  {
    delay(50);
    while(checkbuttons()==4); // Check button debounce
    startbeeping(50);
    jogaxis=2;
    drawjoggingdisplay('Y');
  }
  if(checkbuttons()==5) // Z button pressed
  {
    delay(50);
    while(checkbuttons()==5); // Check button debounce
    startbeeping(50);
    jogaxis=3;
    drawjoggingdisplay('Z');
  }
  if(jogaxis>0)
  {
    if(jogaxis==3) jogdist=0.125;
    else jogdist=0.25;
    jogdir=0;
    if(digitalRead(ROTARY_SW)==LOW)jogdist*=3;
    rotary=rotarycount(300);
    if(rotary!=0)
    {
      if(rotary<0)
      {
        jogdir=1;
        rotary*=-1;
      }
      if(rotary>5) rotary=5;
      jogdist*=float(rotary);
      Serial.print("G91 G0 ");
      switch(jogaxis)
      {
        case 1: Serial.print('X'); break;
        case 2: Serial.print('Y'); break;
        case 3: Serial.print('Z'); break;
      }
      if(jogdir==1) Serial.print('-');
      Serial.print(jogdist,DEC);
      Serial.println(" F200");
      waitforline();
    }
  }
}

void drawjoggingdisplay(char c)
{
  display.clearDisplay();
  display.drawBitmap(0,8,jogging_bmp,jogging_width,jogging_height,WHITE);
  display.setTextColor(WHITE);
  display.setTextSize(2);
  display.setCursor(70,5);
  display.println("Axis");
  display.setTextSize(4);
  display.setCursor(85,33);
  display.println(c);
  display.display();
}

void drawzeroingmode()
{
  if(firsttime==true)
  {
    firsttime=false;
    startbeeping(50);
    drawzeroingdisplay('?');
  }
  if(checkbuttons()==1)
  {
    delay(50);
    while(checkbuttons()==1); // Check button debounce
    modenum=1;
    firsttime=true;
    startbeeping(50);
    return;
  }
  if(checkbuttons()==3) // X button pressed
  {
    delay(50);
    while(checkbuttons()==3); // Check button debounce
    startbeeping(50);
    Serial.println("G10 L20 P1 X0");
    waitforline();
    startbeeping(100);
    drawzeroingdisplay('X');
  }
  if(checkbuttons()==4) // Y button pressed
  {
    delay(50);
    while(checkbuttons()==4); // Check button debounce
    startbeeping(50);
    Serial.println("G10 L20 P1 Y0");
    waitforline();
    startbeeping(100);
    drawzeroingdisplay('Y');
  }
  if(checkbuttons()==5) // Z button pressed
  {
    delay(50);
    while(checkbuttons()==5); // Check button debounce
    startbeeping(50);
    Serial.println("G10 L20 P1 Z0");
    waitforline();
    startbeeping(100);
    drawzeroingdisplay('Z');
  }
}

void drawzeroingdisplay(char c)
{
  display.clearDisplay();
  display.drawBitmap(0,8,zeroing_bmp,zeroing_width,zeroing_height,WHITE);
  display.setTextColor(WHITE);
  display.setTextSize(2);
  display.setCursor(70,5);
  display.println("Axis");
  display.setTextSize(4);
  display.setCursor(85,33);
  display.println(c);
  display.display();
}

void drawfocusingmode()
{
  if(firsttime==true)
  {
    firsttime=false;
    if(laseron==false)
    {
      laseron=true;
      startbeeping(100);
      display.clearDisplay();
      display.drawBitmap(0,0,focusing_bmp,focusing_width,focusing_height,WHITE);
      display.display();
      Serial.println(FOCUSGRBL);
      waitforline();
    }
    else
    {
      laseron=false;
      startbeeping(50);
      display.clearDisplay();
      display.drawBitmap(0,0,focusingoff_bmp,focusingoff_width,focusingoff_height,WHITE);
      display.display();
      Serial.println("M5");
      waitforline();
    }
  }
  if(checkbuttons()==1)
  {
    delay(50);
    while(checkbuttons()==1); // Check button debounce
    modenum=1;
    firsttime=true;
    startbeeping(50);
    return;
  }
}

void waitforline()
{
  char c=0;
  while(c!=10)
  {
    if(Serial.available()>0)
    {
      c=Serial.read();
    }
    if(checkbuttons()==1)
    {
      delay(50);
      while(checkbuttons()==1); // Check button debounce
      return;
    }
  }
}

int checkbuttons()
{
  if(digitalRead(SW_1)==LOW) return 1;
  if(digitalRead(SW_2)==LOW) return 2;
  if(digitalRead(SW_3)==LOW) return 3;
  if(digitalRead(SW_4)==LOW) return 4;
  if(digitalRead(SW_5)==LOW) return 5;
  if(digitalRead(ROTARY_SW)==LOW) return 6;
  return 0;
}

int rotarycount(int t)
{
  int count=0,a;
  long stime=millis();
  while((millis()-stime)<t)
  {
    a=digitalRead(ROTARY_A);
    if(a!=rotary_alast)
    {
      if(digitalRead(ROTARY_B)!=a) count++;
      else count--;
    }
    rotary_alast=a;
  }
  return count;
}

void startbeeping(int bl)
{
  beeplen=bl;
  beepstart=millis();
  beeping=true;
  digitalWrite(BUZZER,HIGH);
}

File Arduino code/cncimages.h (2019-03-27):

#define splash_width 128
#define splash_height 64
static const unsigned char PROGMEM splash_bmp[] = {
  0x00, 0x00, 0x00, 0x00, 0x00, 0x00, 0x00, 0x00, 0x00, 0x00, 0x00, 0x00, 0x00, 0x00, 0x00, 0x00, 
  0x00, 0x00, 0x00, 0x00, 0x00, 0x00, 0x00, 0x00, 0x00, 0x00, 0x00, 0x00, 0x00, 0x00, 0x00, 0x00, 
  0x00, 0x00, 0x00, 0x00, 0x00, 0x00, 0x00, 0x00, 0x00, 0x00, 0x00, 0x00, 0x00, 0x00, 0x00, 0x00, 
  0x00, 0x00, 0x00, 0x00, 0x00, 0x00, 0x00, 0x00, 0x00, 0x00, 0x00, 0x00, 0x00, 0x00, 0x00, 0x00, 
  0x00, 0x00, 0x00, 0x00, 0x00, 0x00, 0x00, 0x00, 0x00, 0x00, 0x00, 0x00, 0x00, 0x00, 0x00, 0x00, 
  0x00, 0x00, 0x00, 0x00, 0xff, 0x81, 0xff, 0xf0, 0x0f, 0xff, 0x80, 0xff, 0x00, 0x00, 0x00, 0x00, 
  0x00, 0x00, 0x00, 0x03, 0xff, 0x81, 0xff, 0xfc, 0x0f, 0xff, 0xe0, 0xff, 0x00, 0x00, 0x00, 0x00, 
  0x00, 0x00, 0x00, 0x07, 0xff, 0x81, 0xff, 0xff, 0x0f, 0xff, 0xf0, 0xff, 0x00, 0x00, 0x00, 0x00, 
  0x00, 0x00, 0x00, 0x0f, 0xff, 0x81, 0xff, 0xff, 0x8f, 0xff, 0xf8, 0xff, 0x00, 0x00, 0x00, 0x00, 
  0x00, 0x00, 0x00, 0x1f, 0xff, 0x81, 0xff, 0xff, 0x8f, 0xff, 0xf8, 0xff, 0x00, 0x00, 0x00, 0x00, 
  0x00, 0x00, 0x00, 0x3f, 0xff, 0x81, 0xff, 0xff, 0xcf, 0xff, 0xf8, 0xff, 0x00, 0x00, 0x00, 0x00, 
  0x00, 0x00, 0x00, 0x3f, 0xff, 0x81, 0xff, 0xff, 0xcf, 0xff, 0xf8, 0xff, 0x00, 0x00, 0x00, 0x00, 
  0x00, 0x00, 0x00, 0x7f, 0xf1, 0x81, 0xfe, 0x7f, 0xcf, 0xf3, 0xf8, 0xff, 0x00, 0x00, 0x00, 0x00, 
  0x00, 0x00, 0x00, 0x7f, 0xc0, 0x01, 0xfe, 0x3f, 0xcf, 0xf3, 0xf8, 0xff, 0x00, 0x00, 0x00, 0x00, 
  0x00, 0x00, 0x00, 0x7f, 0x80, 0x01, 0xfe, 0x3f, 0xcf, 0xf7, 0xf8, 0xff, 0x00, 0x00, 0x00, 0x00, 
  0x00, 0x00, 0x00, 0x7f, 0x8f, 0xe1, 0xff, 0xff, 0xcf, 0xff, 0xf0, 0xff, 0x00, 0x00, 0x00, 0x00, 
  0x00, 0x00, 0x00, 0xff, 0x8f, 0xf1, 0xff, 0xff, 0x8f, 0xff, 0xe0, 0xff, 0x00, 0x00, 0x00, 0x00, 
  0x00, 0x00, 0x00, 0xff, 0x0f, 0xf1, 0xff, 0xff, 0x8f, 0xff, 0xf8, 0xff, 0x00, 0x00, 0x00, 0x00, 
  0x00, 0x00, 0x00, 0x7f, 0x8f, 0xf9, 0xff, 0xff, 0x0f, 0xff, 0xfc, 0xff, 0x00, 0x00, 0x00, 0x00, 
  0x00, 0x00, 0x00, 0x7f, 0x8f, 0xf9, 0xff, 0xfe, 0x0f, 0xff, 0xfc, 0xff, 0x00, 0x00, 0x00, 0x00, 
  0x00, 0x00, 0x00, 0x7f, 0x8f, 0xf9, 0xff, 0xff, 0x0f, 0xff, 0xfc, 0xff, 0x00, 0x00, 0x00, 0x00, 
  0x00, 0x00, 0x00, 0x7f, 0xcf, 0xf9, 0xff, 0xff, 0x0f, 0xf1, 0xfc, 0xff, 0x80, 0x00, 0x00, 0x00, 
  0x00, 0x00, 0x00, 0x7f, 0xff, 0xf9, 0xfe, 0xff, 0x0f, 0xf1, 0xfe, 0xff, 0xe0, 0x00, 0x00, 0x00, 
  0x00, 0x00, 0x00, 0x3f, 0xff, 0xf9, 0xfe, 0xff, 0x8f, 0xff, 0xfc, 0xff, 0xe0, 0x00, 0x00, 0x00, 
  0x00, 0x00, 0x00, 0x3f, 0xff, 0xf9, 0xfe, 0x7f, 0x8f, 0xff, 0xfc, 0x7f, 0xe0, 0x00, 0x00, 0x00, 
  0x00, 0x00, 0x00, 0x1f, 0xff, 0xf1, 0xfe, 0x7f, 0xcf, 0xff, 0xfc, 0x7f, 0xe0, 0x00, 0x00, 0x00, 
  0x00, 0x00, 0x00, 0x0f, 0xff, 0xf1, 0xfe, 0x3f, 0xcf, 0xff, 0xf8, 0x3f, 0xe0, 0x00, 0x00, 0x00, 
  0x00, 0x00, 0x00, 0x07, 0xff, 0xe1, 0xfe, 0x3f, 0xcf, 0xff, 0xf0, 0x1f, 0xe0, 0x00, 0x00, 0x00, 
  0x00, 0x00, 0x00, 0x01, 0xff, 0xc1, 0xfe, 0x3f, 0xef, 0xff, 0xe0, 0x0f, 0xe0, 0x00, 0x00, 0x00, 
  0x00, 0x00, 0x00, 0x00, 0x7f, 0x00, 0x00, 0x00, 0x00, 0x00, 0x00, 0x00, 0x00, 0x00, 0x00, 0x00, 
  0x00, 0x00, 0x00, 0x00, 0x00, 0x00, 0x00, 0x00, 0x00, 0x00, 0x00, 0x00, 0x00, 0x00, 0x00, 0x00, 
  0x00, 0x00, 0x00, 0x00, 0x00, 0x00, 0x00, 0x00, 0x00, 0x00, 0x00, 0x00, 0x00, 0x00, 0x00, 0x00, 
  0x00, 0x00, 0x00, 0x00, 0x00, 0x00, 0x00, 0x00, 0x00, 0x00, 0x00, 0x00, 0x00, 0x00, 0x00, 0x00, 
  0x00, 0x00, 0x00, 0x00, 0x00, 0x00, 0x00, 0x00, 0x00, 0x00, 0x00, 0x00, 0x00, 0x00, 0x00, 0x00, 
  0x03, 0xe0, 0x00, 0x00, 0x00, 0x00, 0x00, 0x00, 0x00, 0x00, 0x00, 0x00, 0x00, 0x00, 0x00, 0x00, 
  0x0f, 0xfc, 0x00, 0x00, 0x00, 0x00, 0x00, 0x00, 0x0f, 0xf0, 0x00, 0x00, 0x00, 0x00, 0x07, 0xf0, 
  0x1f, 0xfe, 0x00, 0x00, 0x00, 0x00, 0x00, 0x00, 0x0f, 0xf0, 0x00, 0x00, 0x00, 0x00, 0x07, 0xf0, 
  0x7f, 0xff, 0x00, 0x00, 0x00, 0x00, 0x00, 0x00, 0x0f, 0xf0, 0x00, 0x00, 0x00, 0x00, 0x07, 0xf0, 
  0x7f, 0xff, 0x80, 0x00, 0x00, 0x00, 0x00, 0x00, 0x0f, 0xf0, 0x00, 0x00, 0x00, 0x00, 0x07, 0xf0, 
  0xff, 0xff, 0x80, 0x00, 0x00, 0x00, 0x00, 0x00, 0x0f, 0xf0, 0x00, 0x00, 0x00, 0x00, 0x07, 0xf0, 
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
};
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

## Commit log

2019-03-27 First upload of 3D files for case making.
    [cncminipendant.scad, cncminipendant_bottom.stl, cncminipendant_dialbase.stl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]
2019-03-27 First upload of Arduino code for ESP32.
